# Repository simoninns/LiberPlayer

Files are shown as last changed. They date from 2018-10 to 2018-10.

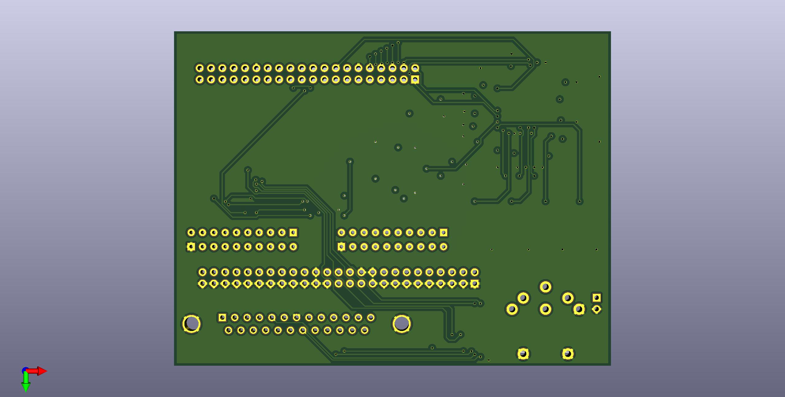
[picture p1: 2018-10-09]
KiCAD/LiberPlayer/PCB render - bottom.jpg

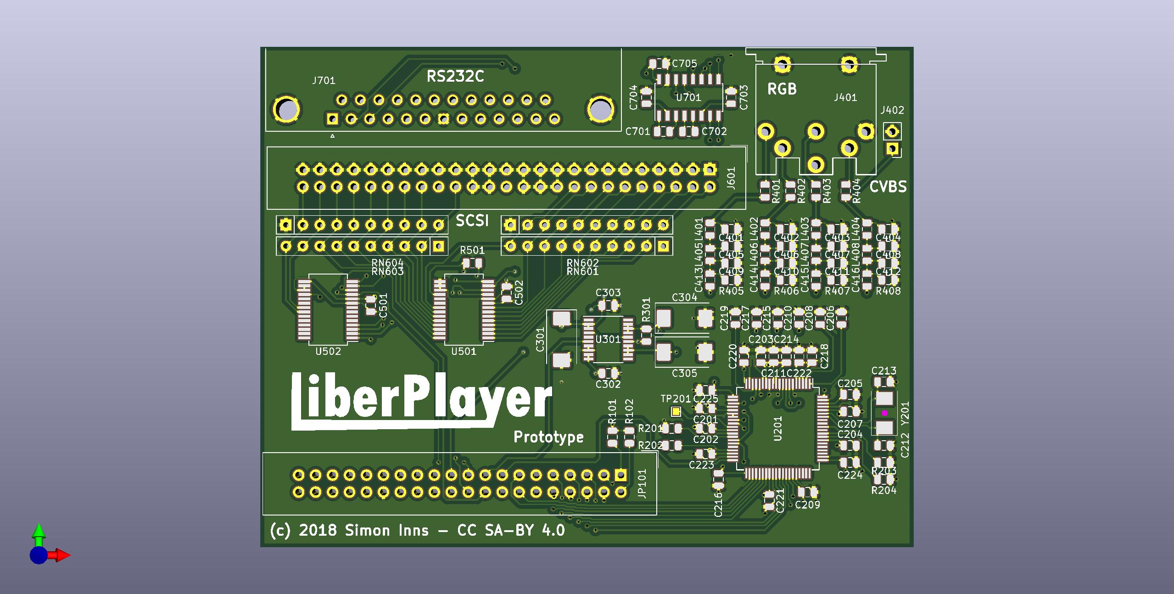
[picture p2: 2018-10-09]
KiCAD/LiberPlayer/PCB render - top.jpg

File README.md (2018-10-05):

# LiberPlayer
LiberPlayer is a LaserDisc video player emulator designed as part of the Domesday86 project.

This project is beta and highly experimental - you won't find anything useful in this repository at the moment unless you are directly involved in the project's development.

For more detail of the Domesday86 project please see https://www.domesday86.com

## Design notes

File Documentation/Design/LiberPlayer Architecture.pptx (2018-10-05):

## High-level architecture (Phase 1)

RGB

Video digitizer

LaserDisc video image file-handing

Player control

Video mixer

CVBS

HDMI

SD Card

Player emulation

RS232C

SCSI-1

## High-level architecture (Phase 2)

RGB

Video digitizer

LaserDisc video image file-handing

Player control

Video mixer

Audio DAC

CVBS

HDMI

SCART

SD Card

Player emulation

Stereo Audio

RS232C

SCSI-1

## High-level architecture (Phase 3)

RGB

Video digitizer

LaserDisc video image file-handing

Player control

Video mixer

Audio DAC

OLED Display

CVBS

HDMI

SCART

SD Card

Ethernet

Player emulation

Stereo Audio

RS232C

SCSI-1

Control Panel

IR

## Video Digitizer

BNC

CVBS

RGB

TI TVP5146

FPGA

Databus

Acorn RGB

I2C

Frame-buffer

HPS

## Player control

DB25

50 pin IDC

RS232C

MAX3232

FPGA

5V to 3V3 converter

SCSI-1

Termination

exFAT MicroSD

SD Card EFM data

HPS

## LaserDisc video image (and audio)

FPGA

HDMI

Frame-buffer

SD Card Video data

HPS

exFAT MicroSD

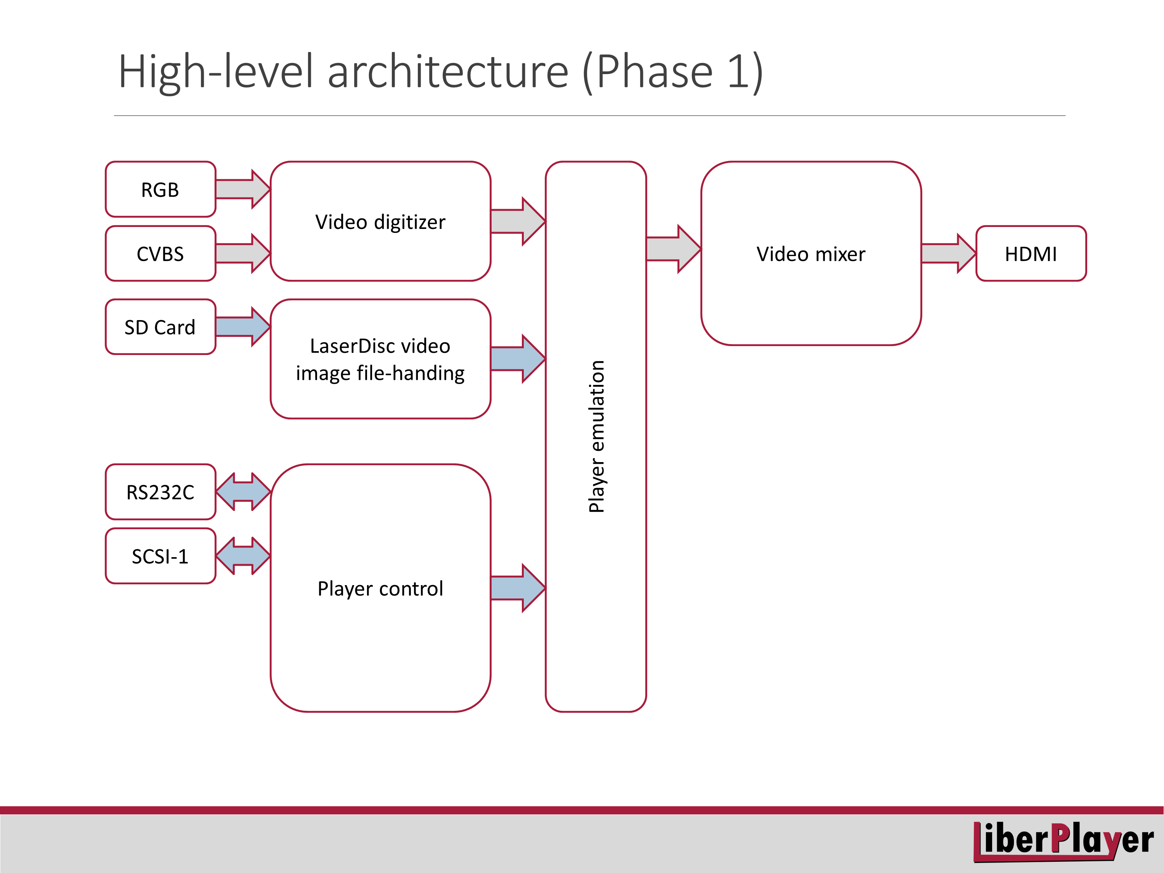
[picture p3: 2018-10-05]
Documentation/Design/LiberPlayer Architecture PNG/Slide1.PNG

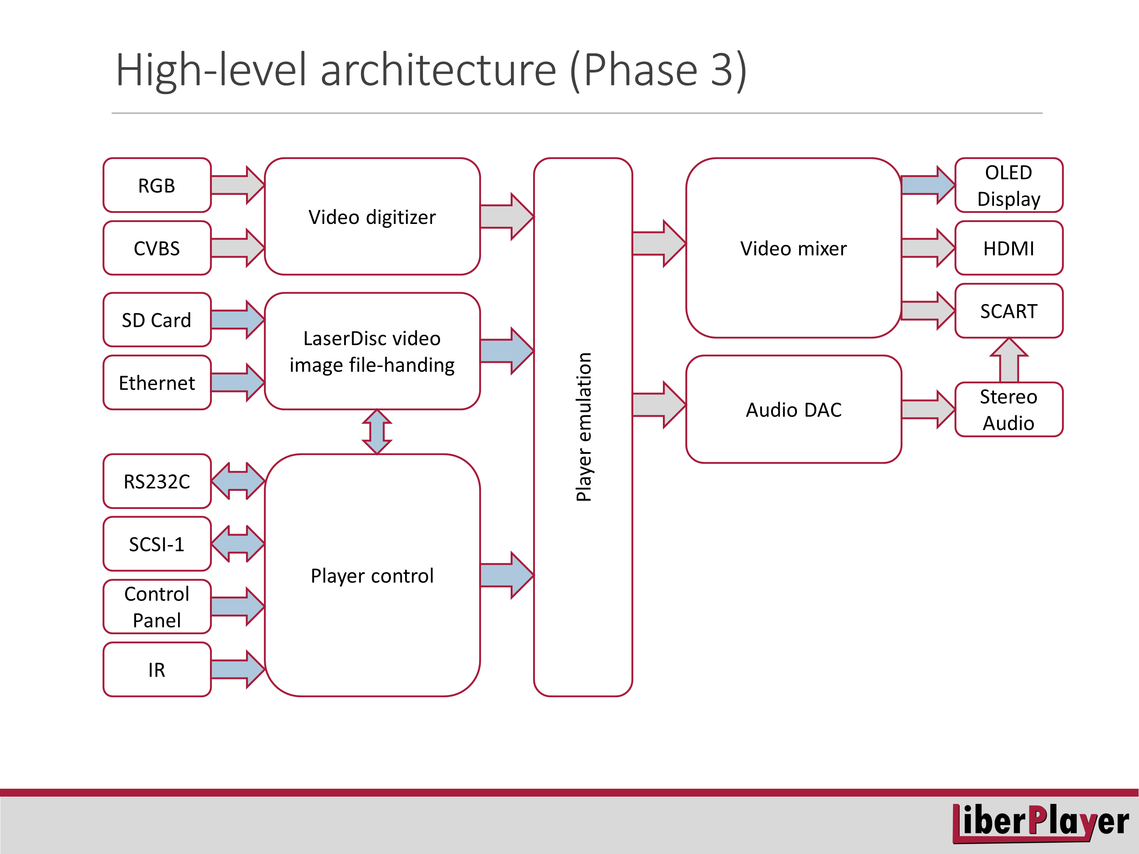
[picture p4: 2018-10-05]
Documentation/Design/LiberPlayer Architecture PNG/Slide3.PNG

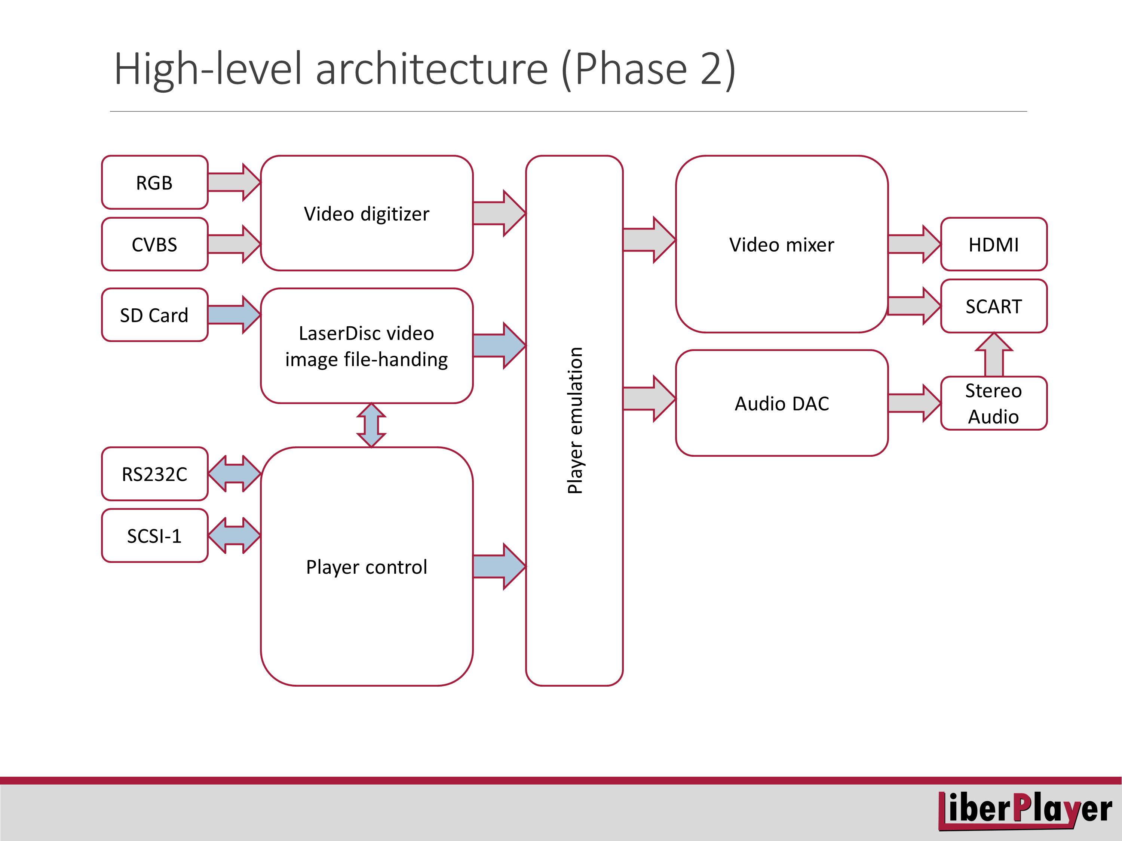
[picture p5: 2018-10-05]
Documentation/Design/LiberPlayer Architecture PNG/Slide2.PNG

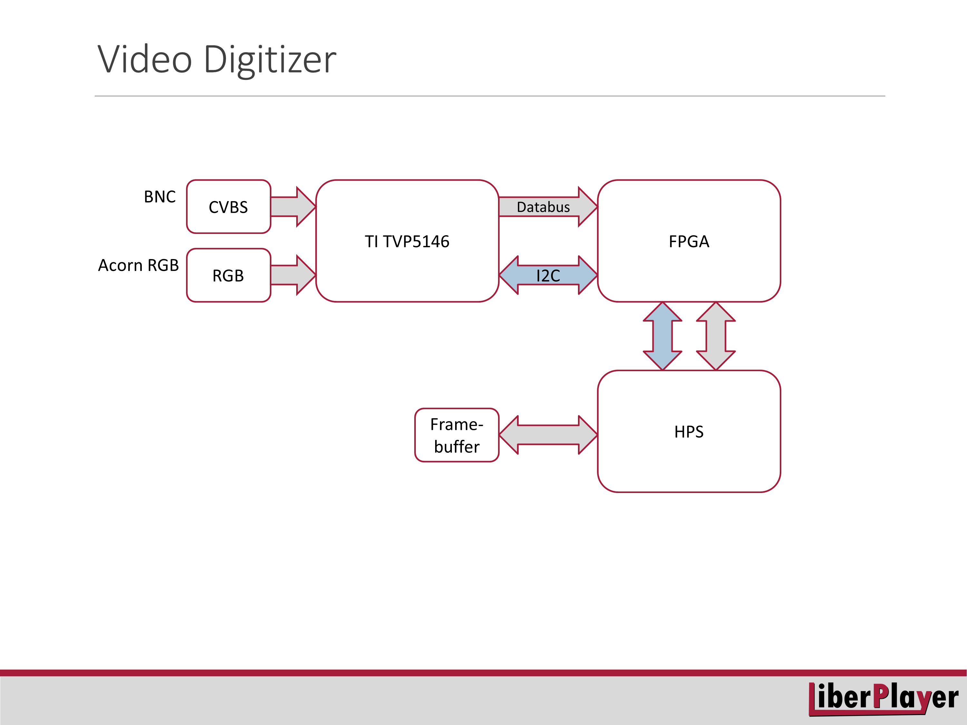
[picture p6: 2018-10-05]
Documentation/Design/LiberPlayer Architecture PNG/Slide4.PNG

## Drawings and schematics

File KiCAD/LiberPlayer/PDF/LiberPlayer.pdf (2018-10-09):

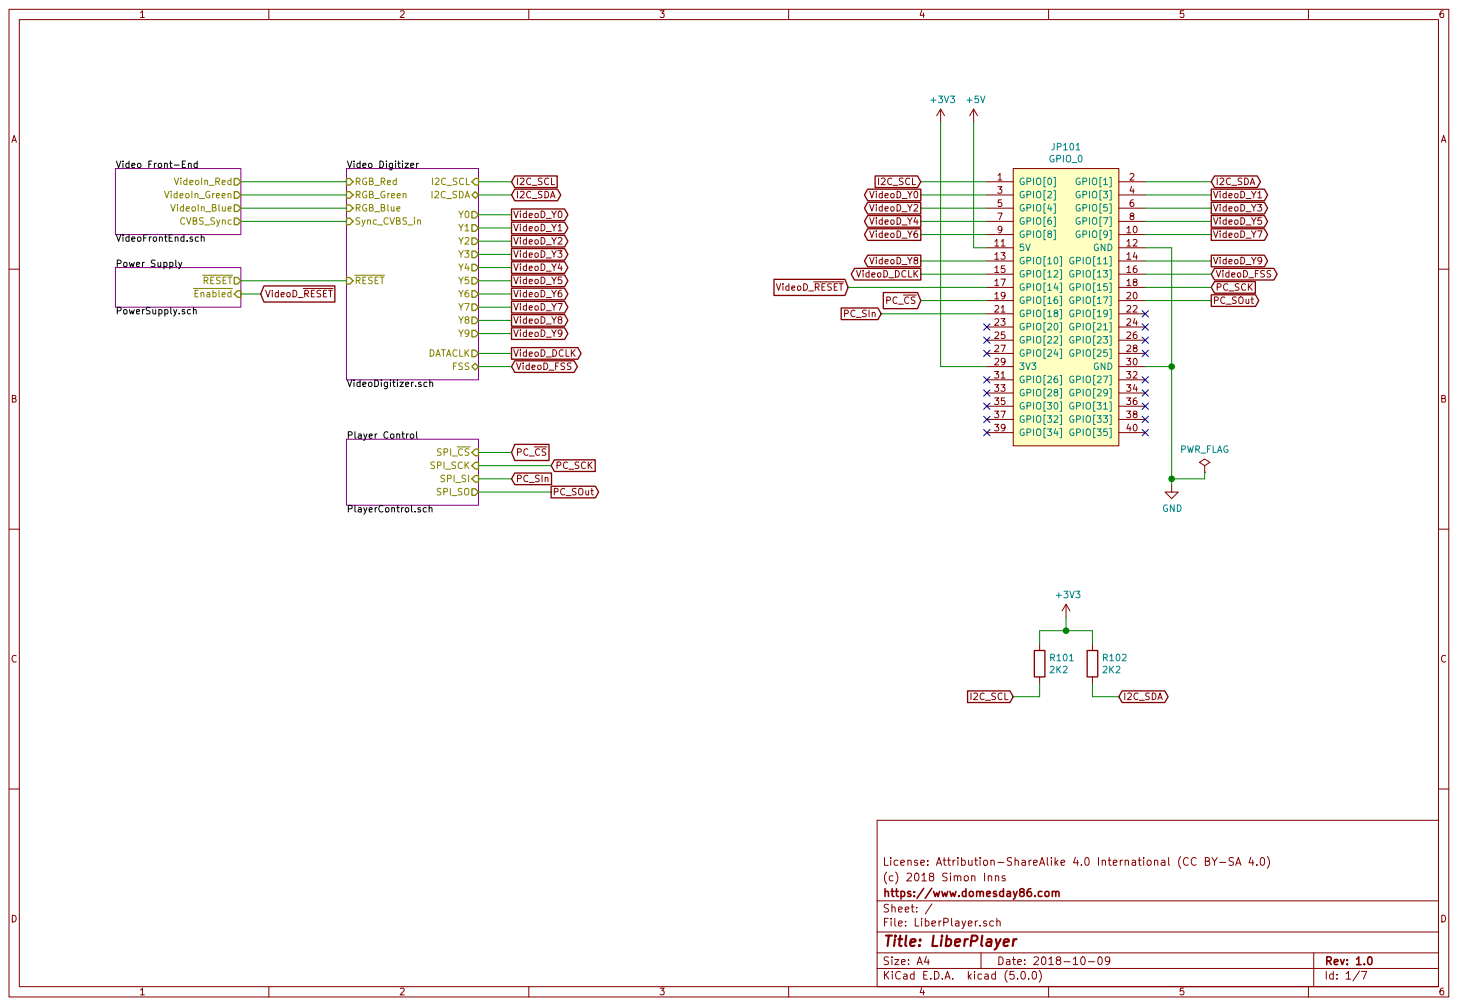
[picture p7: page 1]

License: Attribution-ShareAlike 4.0 International (CC BY-SA 4.0)
(c) 2018 Simon Inns
File: LiberPlayer.sch Sheet: / https://www.domesday86.com

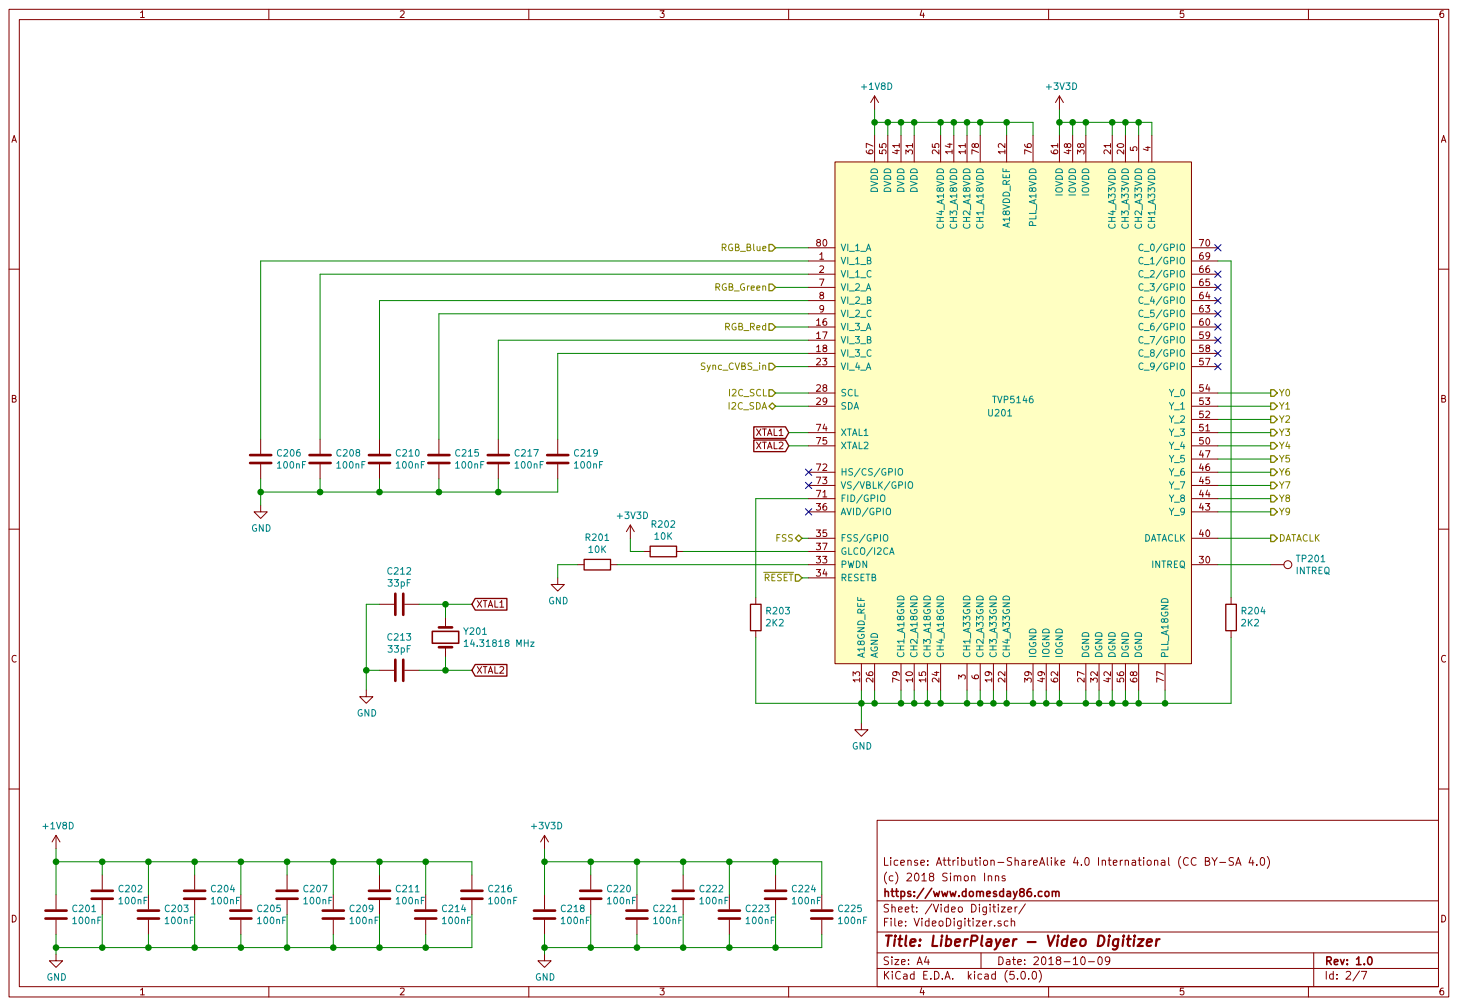
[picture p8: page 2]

6 C_6/GPIO 60 IOVDD 61 IOGND 62 C_5/GPIO 63 C_4/GPIO 64 C_3/GPIO 65 C_2/GPIO 66 DVDD 67 DGND 68 C_1/GPIO 69 VI_2_A 7 C_0/GPIO 70 FID/GPIO 71 HS/CS/GPIO 72 VS/VBLK/GPIO 73 XTAL1 74 XTAL2 75 PLL_A18VDD 76 PLL_A18GND 77 CH1_A18VDD 78 CH1_A18GND 79 VI_2_B 8 VI_1_A 80 VI_2_C 9 U201 TVP5146 TP201

5 Y_4 50 Y_3 51 Y_2 52 Y_1 53 Y_0 54 DVDD 55 DGND 56 C_9/GPIO 57 C_8/GPIO 58 C_7/GPIO 59 CH2_A33GND

4 DATACLK 40 DVDD 41 DGND 42 Y_9 43 Y_8 44 Y_7 45 Y_6 46 Y_5 47 IOVDD 48 IOGND 49 CH2_A33VDD

License: Attribution-ShareAlike 4.0 International (CC BY-SA 4.0) C201

(c) 2018 Simon Inns
https://www.domesday86.com
Sheet: /Video Digitizer/
File: VideoDigitizer.sch
Id: 2/7 Title: LiberPlayer - Video Digitizer

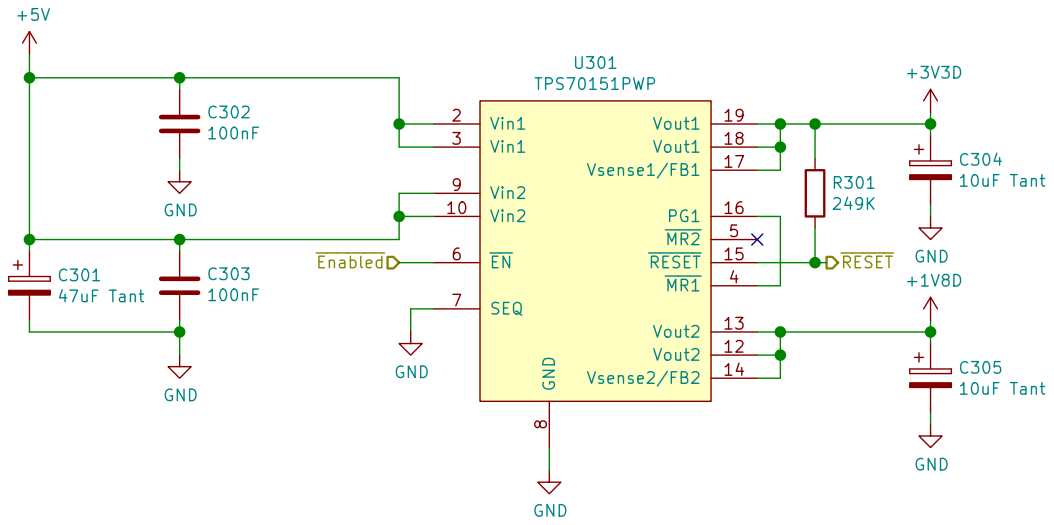
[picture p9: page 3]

(c) 2018 Simon Inns
https://www.domesday86.com
Sheet: /Power Supply/
File: PowerSupply.sch
Id: 3/7 Title: LiberPlayer - Power Supply

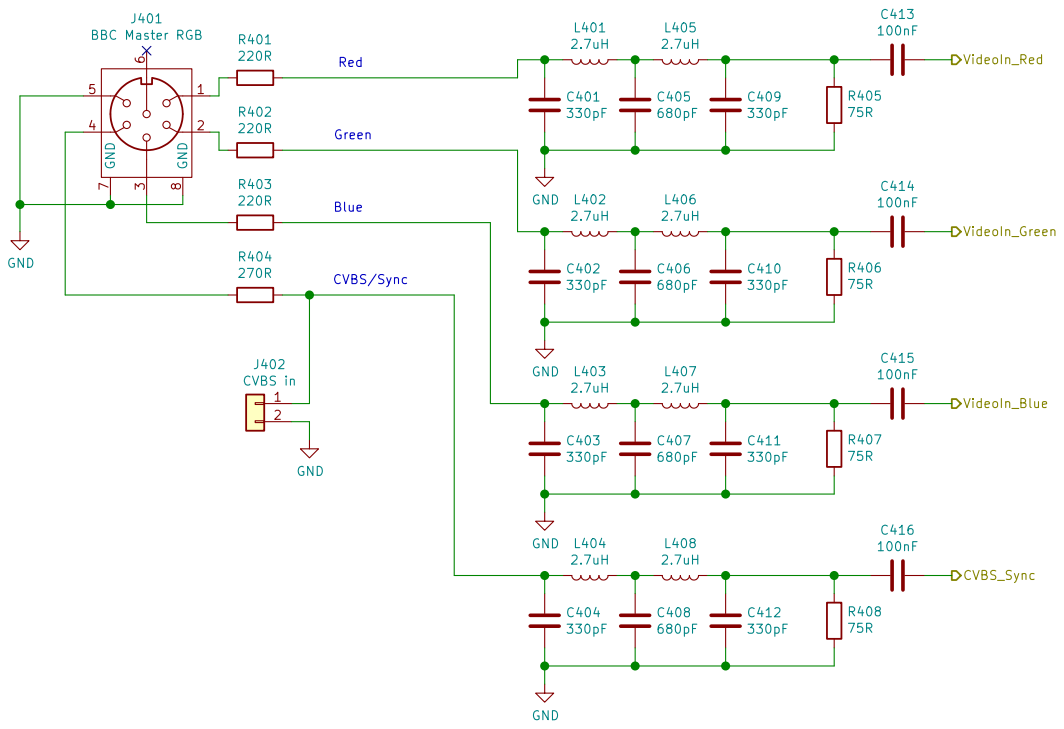
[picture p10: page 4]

License: Attribution-ShareAlike 4.0 International (CC BY-SA 4.0)
(c) 2018 Simon Inns
File: VideoFrontEnd.sch Sheet: /Video Front-End/ https://www.domesday86.com

Id: 4/7 Title: LiberPlayer - Video Front-End

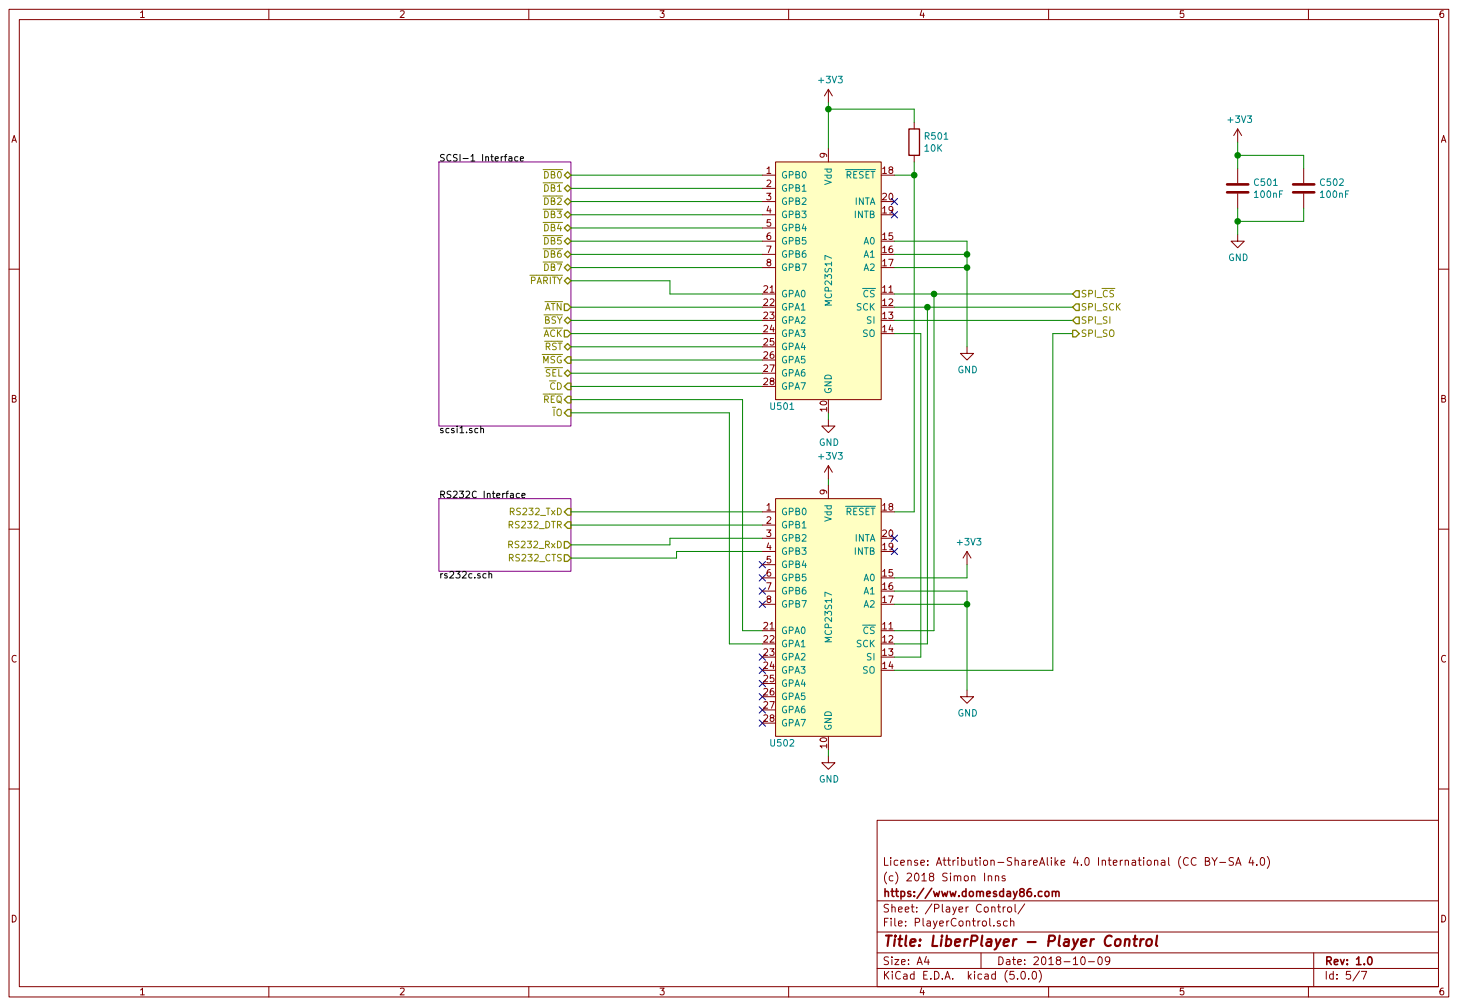
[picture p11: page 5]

BSY RST SEL ATN

License: Attribution-ShareAlike 4.0 International (CC BY-SA 4.0)
(c) 2018 Simon Inns
https://www.domesday86.com
Sheet: /Player Control/
File: PlayerControl.sch
Id: 5/7 Title: LiberPlayer - Player Control

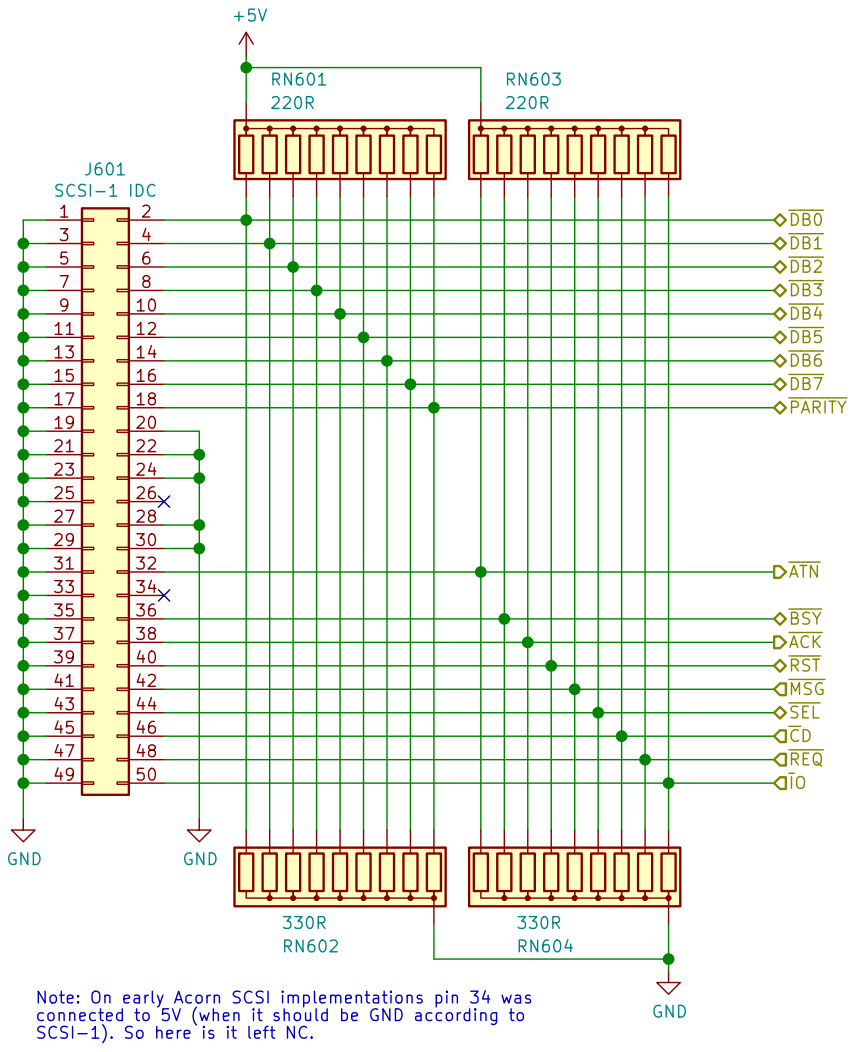
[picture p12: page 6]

17 | J601 SCSI-1 IDC GND | GND 18

9 | | 10
11 | | 12
13 | | 14
15 | | 16

19 | | 20
21 | | 22
23 | | 24

29 | 30
31 | 32

BSY RST SEL ATN

37 | 38
39 | 40
41 | 42
43 | 44
45 | 46
47 | 48
49 | 50

Note: On early Acorn SCSI implementations pin 34 was
connected to 5V (when it should be GND according to
SCSI-1). So here is it left NC.

License: Attribution-ShareAlike 4.0 International (CC BY-SA 4.0)
(c) 2018 Simon Inns
https://www.domesday86.com
File: scsi1.sch Sheet: /Player Control/SCSI-1 Interface/
Id: 6/7 Title: LiberPlayer - SCSI-1 Interface

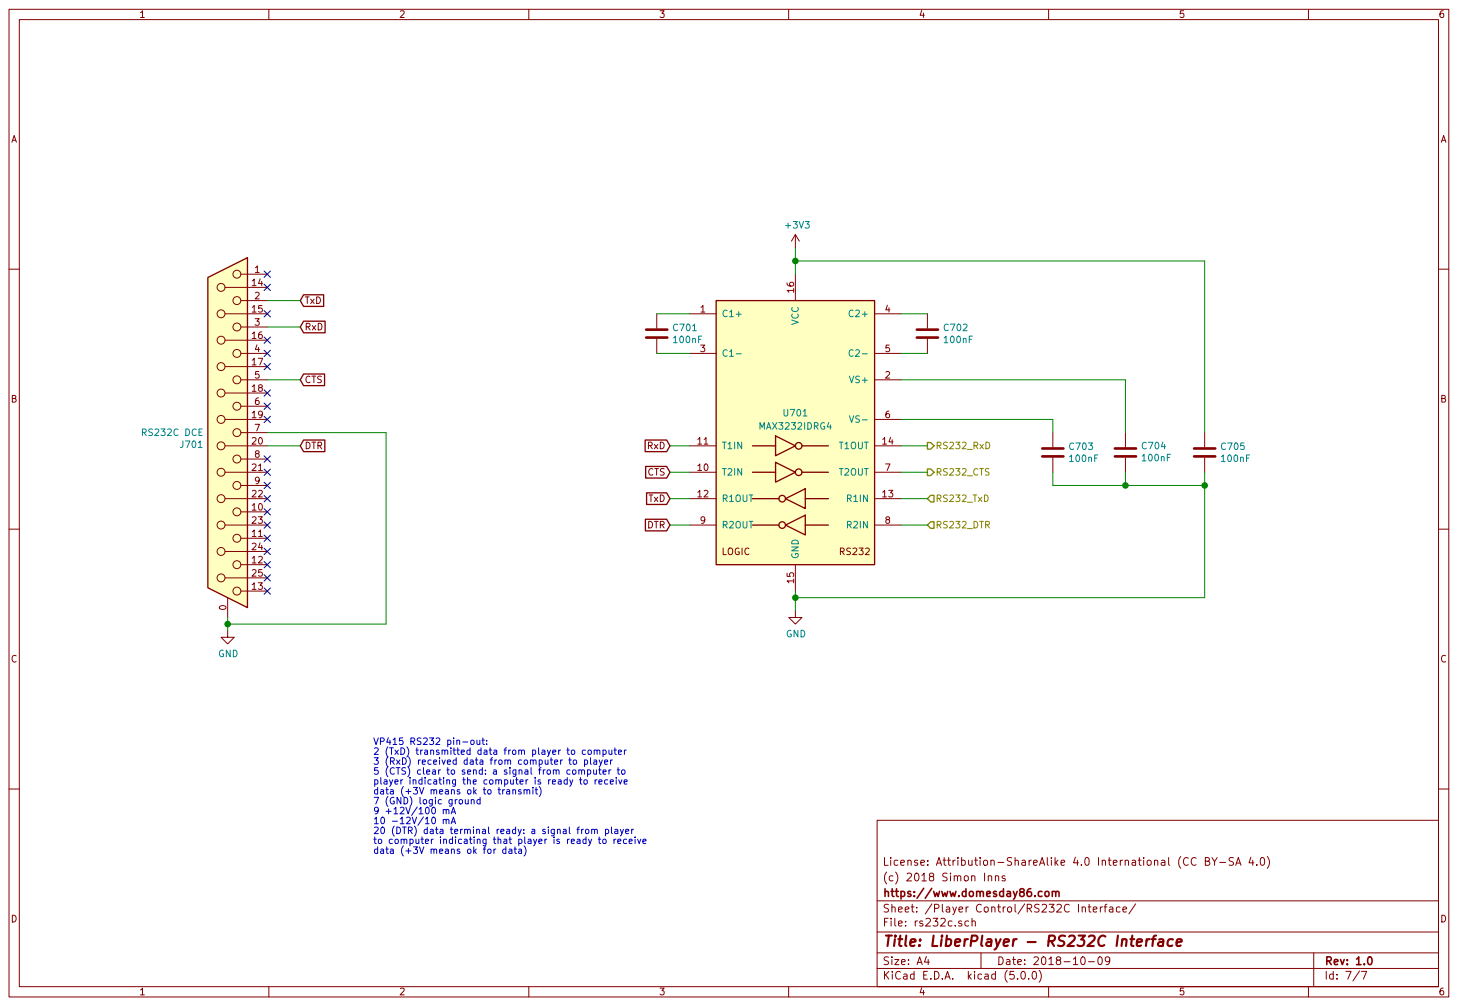
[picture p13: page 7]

VP415 RS232 pin-out:
2 (TxD) transmitted data from player to computer
3 (RxD) received data from computer to player
5 (CTS) clear to send: a signal from computer to
player indicating the computer is ready to receive
data (+3V means ok to transmit)
7 (GND) logic ground
20 (DTR) data terminal ready: a signal from player
to computer indicating that player is ready to receive

(c) 2018 Simon Inns
https://www.domesday86.com
File: rs232c.sch Sheet: /Player Control/RS232C Interface/
Id: 7/7 Title: LiberPlayer - RS232C Interface

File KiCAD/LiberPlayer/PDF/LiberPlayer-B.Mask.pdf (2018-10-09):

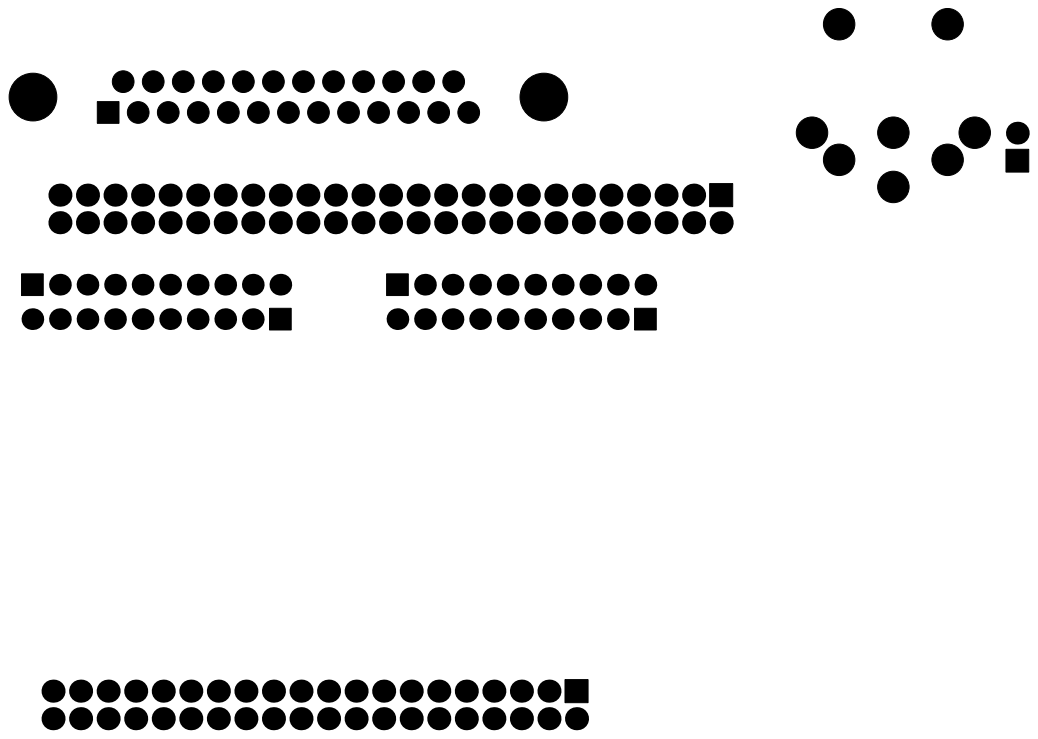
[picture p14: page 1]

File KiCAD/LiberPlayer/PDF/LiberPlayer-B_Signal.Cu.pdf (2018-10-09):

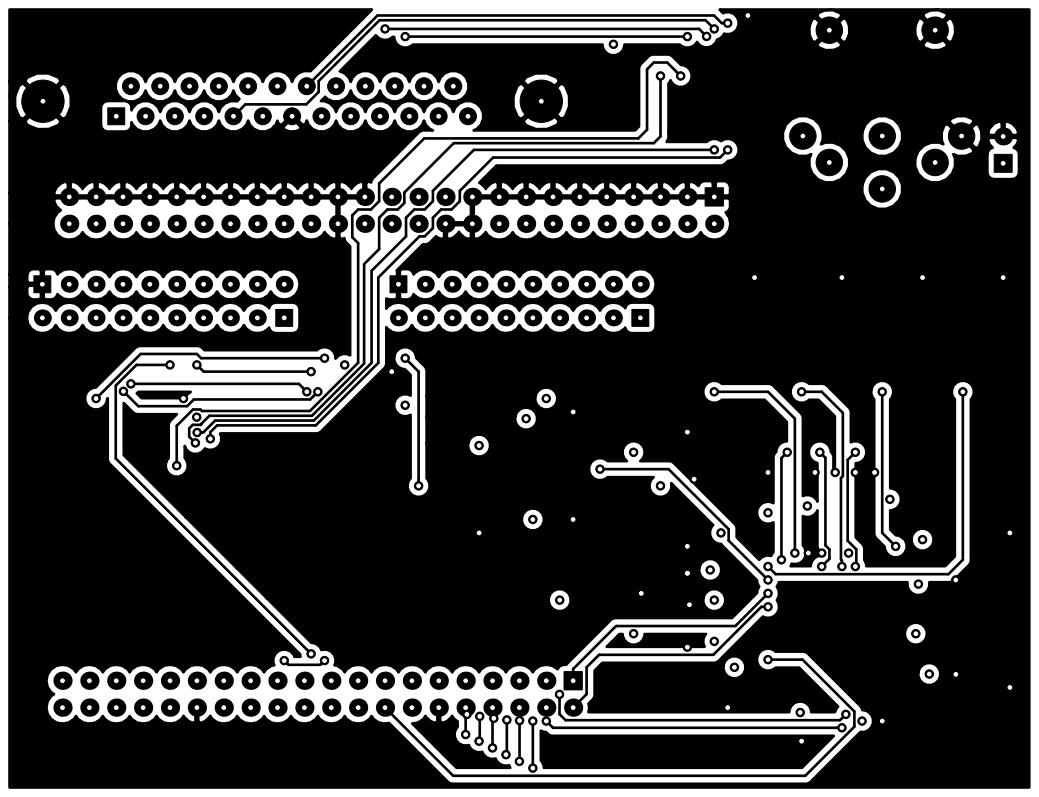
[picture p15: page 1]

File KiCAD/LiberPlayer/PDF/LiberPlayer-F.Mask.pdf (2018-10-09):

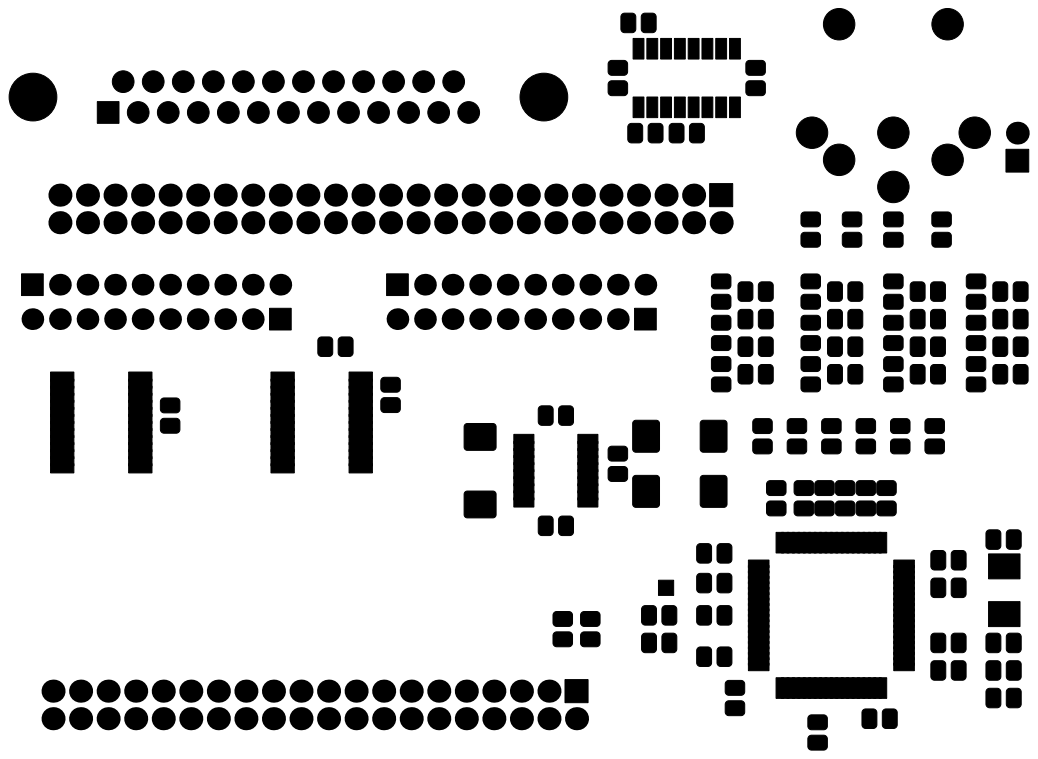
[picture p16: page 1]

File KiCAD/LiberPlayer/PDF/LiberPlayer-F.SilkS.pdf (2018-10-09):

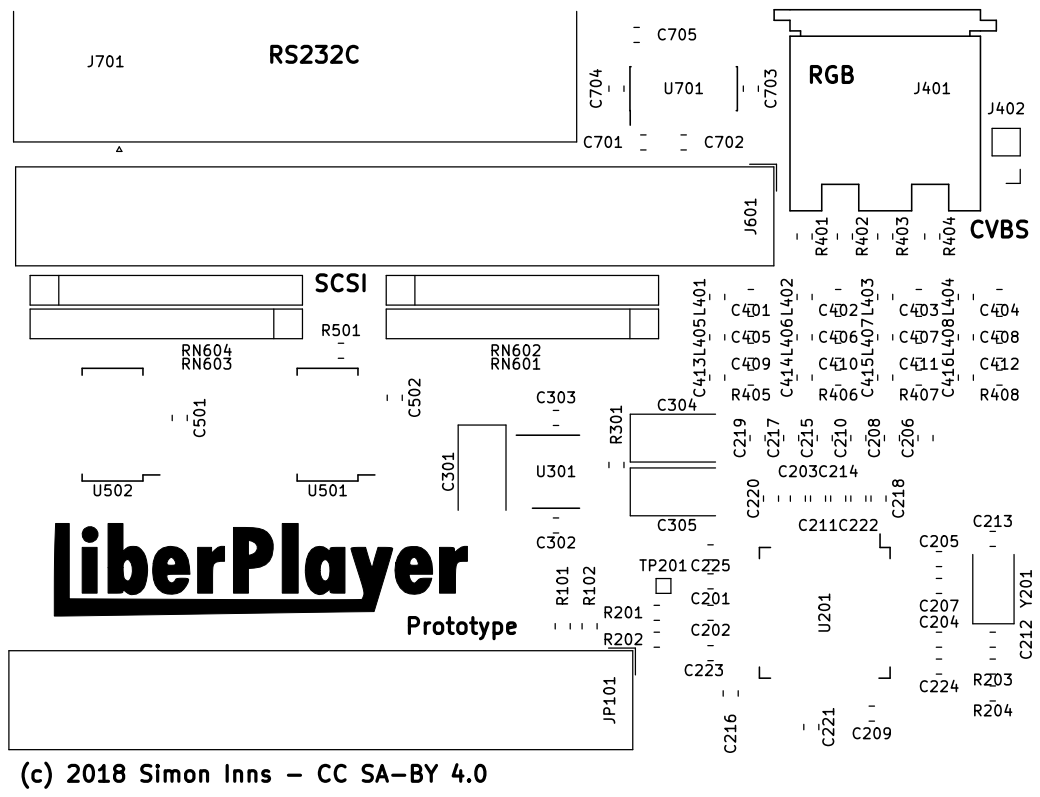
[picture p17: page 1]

(c) 2018 Simon Inns - CC SA-BY 4.0

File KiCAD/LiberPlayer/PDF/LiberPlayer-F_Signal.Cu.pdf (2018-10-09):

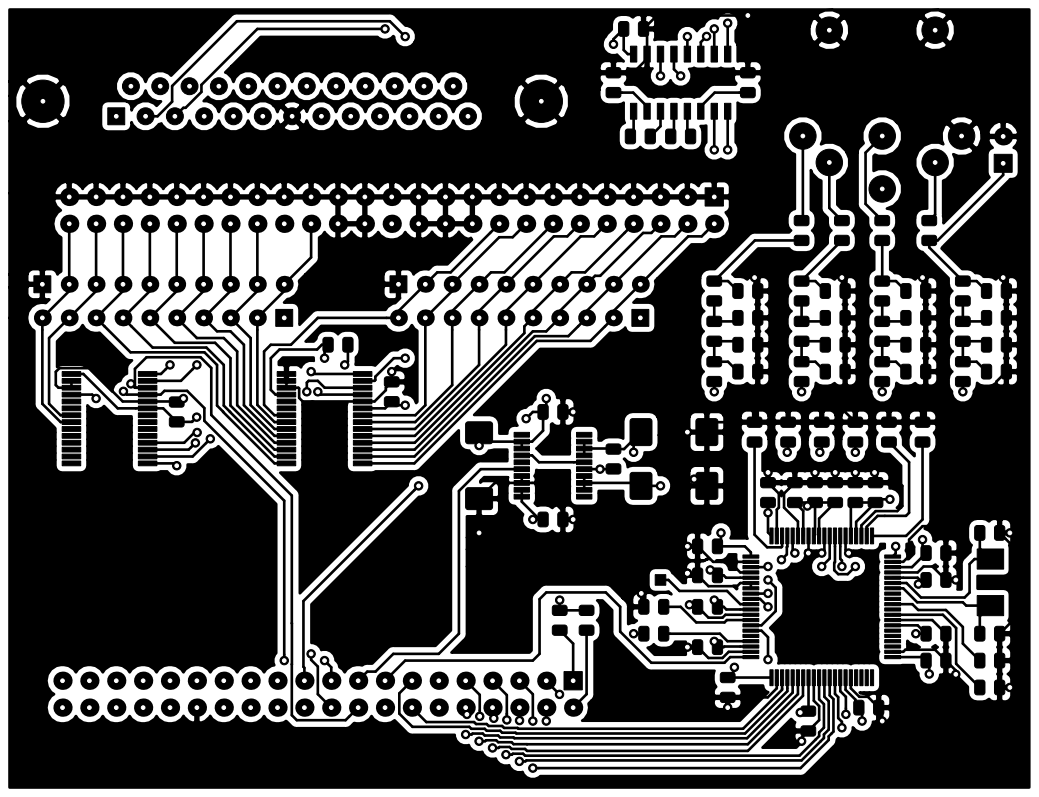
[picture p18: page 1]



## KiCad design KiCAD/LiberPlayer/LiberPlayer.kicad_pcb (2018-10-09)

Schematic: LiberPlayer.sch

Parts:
JP101: GPIO_0; IDC-Header_2x20_P2.54mm_Vertical
R101, R102: 2K2; R_0805_2012Metric

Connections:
+3V3: JP101.29, R101.1, R102.1; also elsewhere on the board
+5V: JP101.11; also elsewhere on the board
GND: JP101.12, JP101.30; also elsewhere on the board
I2C_SCL: JP101.1, R101.2; also elsewhere on the board
I2C_SDA: JP101.2, R102.2; also elsewhere on the board
PC_SCK: JP101.18; also elsewhere on the board
PC_SIn: JP101.21; also elsewhere on the board
PC_SOut: JP101.20; also elsewhere on the board
PC_~CS: JP101.19; also elsewhere on the board
VideoD_DCLK: JP101.15; also elsewhere on the board
VideoD_FSS: JP101.16; also elsewhere on the board
VideoD_Y0: JP101.3; also elsewhere on the board
VideoD_Y1: JP101.4; also elsewhere on the board
VideoD_Y2: JP101.5; also elsewhere on the board
VideoD_Y3: JP101.6; also elsewhere on the board
VideoD_Y4: JP101.7; also elsewhere on the board
VideoD_Y5: JP101.8; also elsewhere on the board
VideoD_Y6: JP101.9; also elsewhere on the board
VideoD_Y7: JP101.10; also elsewhere on the board
VideoD_Y8: JP101.13; also elsewhere on the board
VideoD_Y9: JP101.14; also elsewhere on the board
VideoD_~RESET: JP101.17; also elsewhere on the board

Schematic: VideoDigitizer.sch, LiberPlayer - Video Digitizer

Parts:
C201, C202, C203, C204, C205, C206, C207, C208, C209, C210, C211, C214, C215, C216, C217, C218, C219, C220, C221, C222, C223, C224, C225: 100nF; C_0805_2012Metric
C212, C213: 33pF; C_0805_2012Metric
R201, R202: 10K; R_0805_2012Metric
R203, R204: 2K2; R_0805_2012Metric
TP201: INTREQ; TestPoint_Pad_1.0x1.0mm
U201: TVP5146; TQFP-80_12x12mm_P0.5mm
Y201: 14.31818 MHz; Crystal_SMD_0603-2Pin_6.0x3.5mm

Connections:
+1V8D: C201.1, C202.1, C203.1, C204.1, C205.1, C207.1, C209.1, C211.1, C214.1, C216.1, U201.11, U201.12, U201.14, U201.25, U201.31, U201.41, U201.55, U201.67, U201.76, U201.78; also elsewhere on the board
+3V3D: C218.1, C220.1, C221.1, C222.1, C223.1, C224.1, C225.1, R202.2, U201.4, U201.5, U201.20, U201.21, U201.38, U201.48, U201.61; also elsewhere on the board
/Power Supply/~RESET: U201.34; also elsewhere on the board
/Video Digitizer/RGB_Blue: U201.80; also elsewhere on the board
/Video Digitizer/RGB_Green: U201.7; also elsewhere on the board
/Video Digitizer/RGB_Red: U201.16; also elsewhere on the board
/Video Front-End/CVBS_Sync: U201.23; also elsewhere on the board
GND: C201.2, C202.2, C203.2, C204.2, C205.2, C206.2, C207.2, C208.2, C209.2, C210.2, C211.2, C212.2, C213.2, C214.2, C215.2, C216.2, C217.2, C218.2, C219.2, C220.2, C221.2, C222.2, C223.2, C224.2, C225.2, R201.2, R203.1, R204.1, U201.3, U201.6, U201.10, U201.13, U201.15, U201.19, U201.22, U201.24, U201.26, U201.27, U201.32, U201.39, U201.42, U201.49, U201.56, U201.62, U201.68, U201.77, U201.79; also elsewhere on the board
I2C_SCL: U201.28; also elsewhere on the board
I2C_SDA: U201.29; also elsewhere on the board
unnamed: C206.1, U201.1
unnamed: C208.1, U201.2
unnamed: C210.1, U201.8
unnamed: C215.1, U201.9
unnamed: C217.1, U201.17
unnamed: C219.1, U201.18
unnamed: R201.1, U201.33
unnamed: R202.1, U201.37
unnamed: R203.2, U201.71
unnamed: R204.2, U201.69
unnamed: TP201.1, U201.30
VideoD_DCLK: U201.40; also elsewhere on the board
VideoD_FSS: U201.35; also elsewhere on the board
VideoD_Y0: U201.54; also elsewhere on the board
VideoD_Y1: U201.53; also elsewhere on the board
VideoD_Y2: U201.52; also elsewhere on the board
VideoD_Y3: U201.51; also elsewhere on the board
VideoD_Y4: U201.50; also elsewhere on the board
VideoD_Y5: U201.47; also elsewhere on the board
VideoD_Y6: U201.46; also elsewhere on the board
VideoD_Y7: U201.45; also elsewhere on the board
VideoD_Y8: U201.44; also elsewhere on the board
VideoD_Y9: U201.43; also elsewhere on the board
XTAL1: C212.1, U201.74, Y201.1
XTAL2: C213.1, U201.75, Y201.2

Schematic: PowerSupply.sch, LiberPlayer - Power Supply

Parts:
C301: 47uF Tant; CP_EIA-7343-31_Kemet-D
C302, C303: 100nF; C_0805_2012Metric
C304, C305: 10uF Tant; CP_EIA-7343-31_Kemet-D
R301: 249K; R_0805_2012Metric
U301: TPS70151PWP; TSSOP-20_4.4x6.5mm_P0.65mm

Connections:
+1V8D: C305.1, U301.12, U301.13, U301.14; also elsewhere on the board
+3V3D: C304.1, R301.1, U301.17, U301.18, U301.19; also elsewhere on the board
+5V: C301.1, C302.2, C303.2, U301.2, U301.3, U301.9, U301.10; also elsewhere on the board
/Power Supply/~RESET: R301.2, U301.15; also elsewhere on the board
GND: C301.2, C302.1, C303.1, C304.2, C305.2, U301.7, U301.8; also elsewhere on the board
unnamed: U301.4, U301.16
VideoD_~RESET: U301.6; also elsewhere on the board

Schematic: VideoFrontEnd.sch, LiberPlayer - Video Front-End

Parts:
C401, C402, C403, C404, C409, C410, C411, C412: 330pF; C_0805_2012Metric
C405, C406, C407, C408: 680pF; C_0805_2012Metric
C413, C414, C415, C416: 100nF; C_0805_2012Metric
J401: BBC Master RGB; 6P DIN Socket RS Pro
J402: CVBS in; PinHeader_1x02_P2.54mm_Vertical
L401, L402, L403, L404, L405, L406, L407, L408: 2.7uH; L_0805_2012Metric
R401, R402, R403: 220R; R_0805_2012Metric
R404: 270R; R_0805_2012Metric
R405, R406, R407, R408: 75R; R_0805_2012Metric

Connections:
/Video Digitizer/RGB_Blue: C415.1; also elsewhere on the board
/Video Digitizer/RGB_Green: C414.1; also elsewhere on the board
/Video Digitizer/RGB_Red: C413.1; also elsewhere on the board
/Video Front-End/CVBS_Sync: C416.1; also elsewhere on the board
GND: C401.2, C402.2, C403.2, C404.2, C405.2, C406.2, C407.2, C408.2, C409.2, C410.2, C411.2, C412.2, J401.5, J401.7, J401.8, J402.2, R405.1, R406.1, R407.1, R408.1; also elsewhere on the board
unnamed: C401.1, L401.2, R401.2
unnamed: C402.1, L402.2, R402.2
unnamed: C403.1, L403.2, R403.2
unnamed: C404.1, J402.1, L404.2, R404.2
unnamed: C405.1, L401.1, L405.2
unnamed: C406.1, L402.1, L406.2
unnamed: C407.1, L403.1, L407.2
unnamed: C408.1, L404.1, L408.2
unnamed: C409.1, C413.2, L405.1, R405.2
unnamed: C410.1, C414.2, L406.1, R406.2
unnamed: C411.1, C415.2, L407.1, R407.2
unnamed: C412.1, C416.2, L408.1, R408.2
unnamed: J401.1, R401.1
unnamed: J401.2, R402.1
unnamed: J401.3, R403.1
unnamed: J401.4, R404.1

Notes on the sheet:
Red
Green
Blue
CVBS/Sync

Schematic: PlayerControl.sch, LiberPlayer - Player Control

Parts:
C501, C502: 100nF; C_0805_2012Metric
R501: 10K; R_0805_2012Metric
U501, U502: MCP23S17; SSOP-28_5.3x10.2mm_P0.65mm

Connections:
+3V3: C501.1, C502.1, R501.1, U501.9, U502.9, U502.15; also elsewhere on the board
/Player Control/RS232C Interface/RS232_CTS: U502.4; also elsewhere on the board
/Player Control/RS232C Interface/RS232_DTR: U502.2; also elsewhere on the board
/Player Control/RS232C Interface/RS232_RxD: U502.3; also elsewhere on the board
/Player Control/RS232C Interface/RS232_TxD: U502.1; also elsewhere on the board
/Player Control/SCSI-1 Interface/~ACK: U501.24; also elsewhere on the board
/Player Control/SCSI-1 Interface/~ATN: U501.22; also elsewhere on the board
/Player Control/SCSI-1 Interface/~BSY: U501.23; also elsewhere on the board
/Player Control/SCSI-1 Interface/~C~D: U501.28; also elsewhere on the board
/Player Control/SCSI-1 Interface/~DB0: U501.1; also elsewhere on the board
/Player Control/SCSI-1 Interface/~DB1: U501.2; also elsewhere on the board
/Player Control/SCSI-1 Interface/~DB2: U501.3; also elsewhere on the board
/Player Control/SCSI-1 Interface/~DB3: U501.4; also elsewhere on the board
/Player Control/SCSI-1 Interface/~DB4: U501.5; also elsewhere on the board
/Player Control/SCSI-1 Interface/~DB5: U501.6; also elsewhere on the board
/Player Control/SCSI-1 Interface/~DB6: U501.7; also elsewhere on the board
/Player Control/SCSI-1 Interface/~DB7: U501.8; also elsewhere on the board
/Player Control/SCSI-1 Interface/~I~O: U502.22; also elsewhere on the board
/Player Control/SCSI-1 Interface/~MSG: U501.26; also elsewhere on the board
/Player Control/SCSI-1 Interface/~PARITY: U501.21; also elsewhere on the board
/Player Control/SCSI-1 Interface/~REQ: U502.21; also elsewhere on the board
/Player Control/SCSI-1 Interface/~RST: U501.25; also elsewhere on the board
/Player Control/SCSI-1 Interface/~SEL: U501.27; also elsewhere on the board
GND: C501.2, C502.2, U501.10, U501.15, U501.16, U501.17, U502.10, U502.16, U502.17; also elsewhere on the board
unnamed: R501.2, U501.18, U502.18
unnamed: U501.14, U502.13
PC_SCK: U501.12, U502.12; also elsewhere on the board
PC_SIn: U501.13; also elsewhere on the board
PC_SOut: U502.14; also elsewhere on the board
PC_~CS: U501.11, U502.11; also elsewhere on the board

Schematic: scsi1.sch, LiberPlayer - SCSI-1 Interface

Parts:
J601: SCSI-1 IDC; IDC-Header_2x25_P2.54mm_Vertical
RN601, RN603: 220R; R_Array_SIP10
RN602, RN604: 330R; R_Array_SIP10

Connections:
+5V: RN601.1, RN603.1; also elsewhere on the board
/Player Control/SCSI-1 Interface/~ACK: J601.38, RN603.4, RN604.8; also elsewhere on the board
/Player Control/SCSI-1 Interface/~ATN: J601.32, RN603.2, RN604.10; also elsewhere on the board
/Player Control/SCSI-1 Interface/~BSY: J601.36, RN603.3, RN604.9; also elsewhere on the board
/Player Control/SCSI-1 Interface/~C~D: J601.46, RN603.8, RN604.4; also elsewhere on the board
/Player Control/SCSI-1 Interface/~DB0: J601.2, RN601.2, RN602.10; also elsewhere on the board
/Player Control/SCSI-1 Interface/~DB1: J601.4, RN601.3, RN602.9; also elsewhere on the board
/Player Control/SCSI-1 Interface/~DB2: J601.6, RN601.4, RN602.8; also elsewhere on the board
/Player Control/SCSI-1 Interface/~DB3: J601.8, RN601.5, RN602.7; also elsewhere on the board
/Player Control/SCSI-1 Interface/~DB4: J601.10, RN601.6, RN602.6; also elsewhere on the board
/Player Control/SCSI-1 Interface/~DB5: J601.12, RN601.7, RN602.5; also elsewhere on the board
/Player Control/SCSI-1 Interface/~DB6: J601.14, RN601.8, RN602.4; also elsewhere on the board
/Player Control/SCSI-1 Interface/~DB7: J601.16, RN601.9, RN602.3; also elsewhere on the board
/Player Control/SCSI-1 Interface/~I~O: J601.50, RN603.10, RN604.2; also elsewhere on the board
/Player Control/SCSI-1 Interface/~MSG: J601.42, RN603.6, RN604.6; also elsewhere on the board
/Player Control/SCSI-1 Interface/~PARITY: J601.18, RN601.10, RN602.2; also elsewhere on the board
/Player Control/SCSI-1 Interface/~REQ: J601.48, RN603.9, RN604.3; also elsewhere on the board
/Player Control/SCSI-1 Interface/~RST: J601.40, RN603.5, RN604.7; also elsewhere on the board
/Player Control/SCSI-1 Interface/~SEL: J601.44, RN603.7, RN604.5; also elsewhere on the board
GND: J601.1, J601.3, J601.5, J601.7, J601.9, J601.11, J601.13, J601.15, J601.17, J601.19, J601.20, J601.21, J601.22, J601.23, J601.24, J601.25, J601.27, J601.28, J601.29, J601.30, J601.31, J601.33, J601.35, J601.37, J601.39, J601.41, J601.43, J601.45, J601.47, J601.49, RN602.1, RN604.1; also elsewhere on the board

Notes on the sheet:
Note: On early Acorn SCSI implementations pin 34 was connected to 5V (when it should be GND according to SCSI-1). So here is it left NC.

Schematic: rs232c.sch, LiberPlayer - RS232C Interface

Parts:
C701, C702, C703, C704, C705: 100nF; C_0805_2012Metric
J701: RS232C DCE; DSUB-25_Female_Horizontal_P2.77x2.84mm_EdgePinOffset7.70mm_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
U701: MAX3232IDRG4; SOIC-16_3.9x9.9mm_P1.27mm

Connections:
+3V3: C705.1, U701.16 (VCC); also elsewhere on the board
/Player Control/RS232C Interface/RS232_CTS: U701.7 (T2OUT); also elsewhere on the board
/Player Control/RS232C Interface/RS232_DTR: U701.8 (R2IN); also elsewhere on the board
/Player Control/RS232C Interface/RS232_RxD: U701.14 (T1OUT); also elsewhere on the board
/Player Control/RS232C Interface/RS232_TxD: U701.13 (R1IN); also elsewhere on the board
CTS: J701.5, U701.10 (T2IN)
DTR: J701.20, U701.9 (R2OUT)
GND: C703.2, C704.1, C705.2, J701.0, J701.7, U701.15 (GND); also elsewhere on the board
unnamed: C701.1, U701.1 (C1+)
unnamed: C701.2, U701.3 (C1-)
unnamed: C702.1, U701.4 (C2+)
unnamed: C702.2, U701.5 (C2-)
unnamed: C703.1, U701.6 (VS-)
unnamed: C704.2, U701.2 (VS+)
RxD: J701.3, U701.11 (T1IN)
TxD: J701.2, U701.12 (R1OUT)

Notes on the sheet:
VP415 RS232 pin-out: 2 (TxD) transmitted data from player to computer 3 (RxD) received data from computer to player 5 (CTS) clear to send: a signal from computer to player indicating the computer is ready to receive data (+3V means ok to transmit) 7 (GND) logic ground 9 +12V/100 mA 10 -12V/10 mA 20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

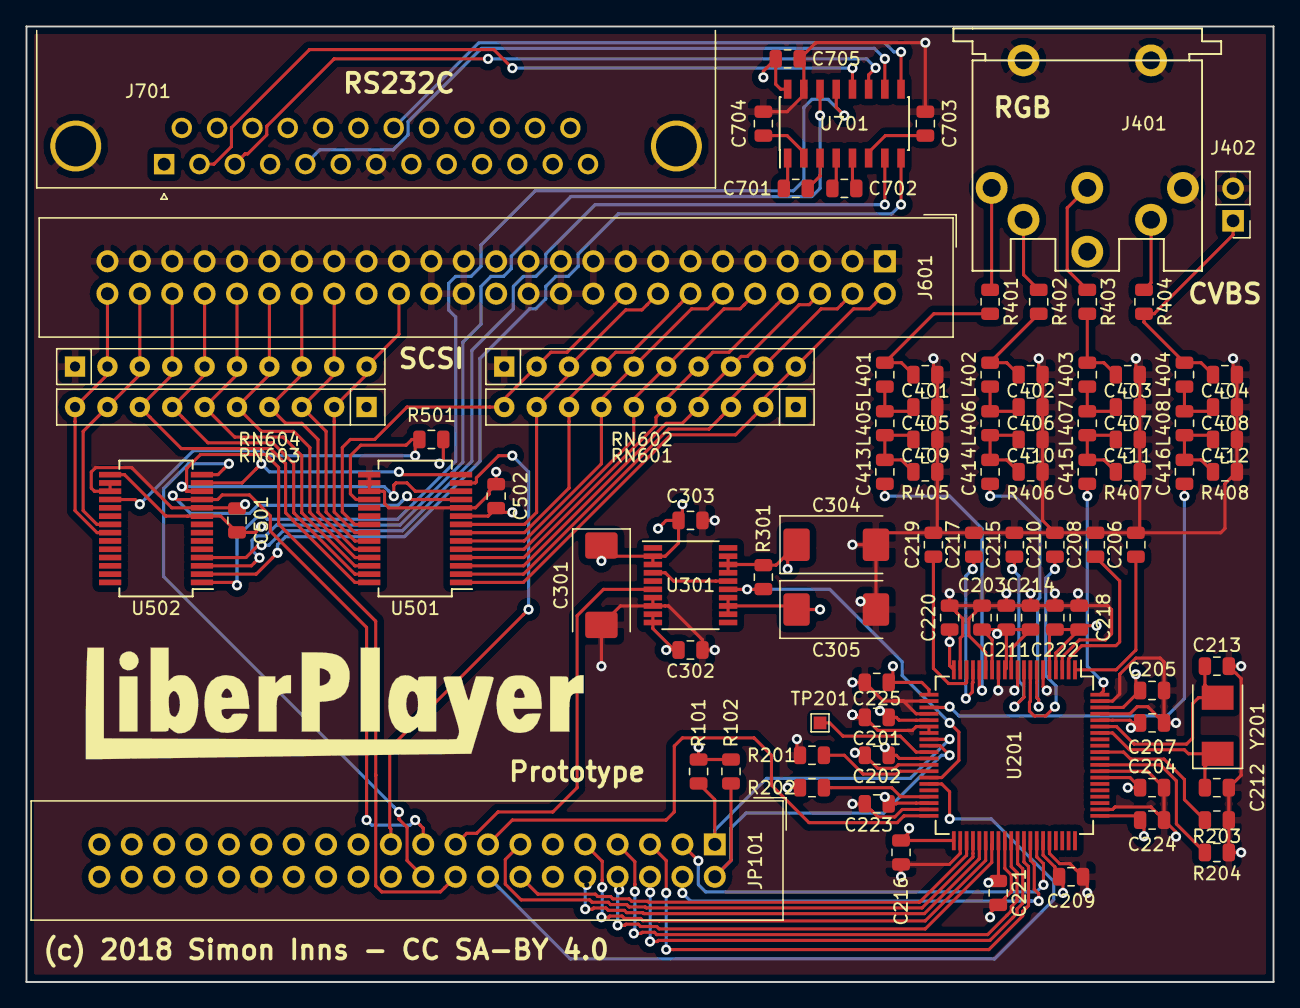
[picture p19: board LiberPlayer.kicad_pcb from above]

Board: 4 copper layers, 97.8 x 74.9 mm, 93 parts (0 on the bottom side), 93 nets.

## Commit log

2018-10-05 Initial sketch of video digitizer design
    [LiberPlayer.kicad_pcb, LiberPlayer.sch, VideoDigitizer.sch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]
2018-10-05 Added video front end and filters
    [LiberPlayer.sch, VideoDigitizer.sch, VideoFrontEnd.sch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]
2018-10-05 Added RS232 interface
    [LiberPlayer.sch, rs232c.sch]
2018-10-05 Added KiCAD gitignore and cleaned up files
2018-10-06 Added GPIO and ADC header library for DE10-Nano
    [LiberPlayer.sch, PowerSupply.sch, VideoDigitizer.sch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]
2018-10-06 Added power supply and test points to design
    [LiberPlayer.sch, PowerSupply.sch, VideoDigitizer.sch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]
2018-10-06 Added SCSI-1 interface, power supply fixes and DE10-Nano interconnection
    [LiberPlayer.sch, PowerSupply.sch, VideoDigitizer.sch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]
2018-10-06 ERC error corrections
    [LiberPlayer.sch, PowerSupply.sch, VideoDigitizer.sch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]
2018-10-07 Added RGB socket symbol and footprint - first pass at allocating all footprints
    [LiberPlayer.sch, PowerSupply.sch, VideoDigitizer.sch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]
2018-10-07 Foot-print assignments and initial PCB creation
    [LiberPlayer.kicad_pcb, PowerSupply.sch, VideoDigitizer.sch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]
2018-10-08 Added I2C front-end to player control (serial and SCSI)
    [LiberPlayer.kicad_pcb, LiberPlayer.sch, PlayerControl.sch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]
2018-10-08 Revised schematic (SPI to SCSI) and board design (incomplete)
    [LiberPlayer.kicad_pcb, LiberPlayer.sch, PlayerControl.sch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]
2018-10-08 Added logo to PCB
    [LiberPlayer.kicad_pcb]
2018-10-09 Finised PCB and added all required support files
    [LiberPlayer-B.Mask.gbr, LiberPlayer-B.SilkS.gbr, LiberPlayer-B_Signal.Cu.gbr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]
